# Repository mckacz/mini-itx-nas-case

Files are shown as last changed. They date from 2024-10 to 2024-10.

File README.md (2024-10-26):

# Mini-ITX NAS case

I've decided to design my own case because I could not find any suitable case for 
a mini-ITX motherboard with two 3.5 HDDs and no ATX power supply. :sunglasses:

| Render | Assembled |
|---|---|
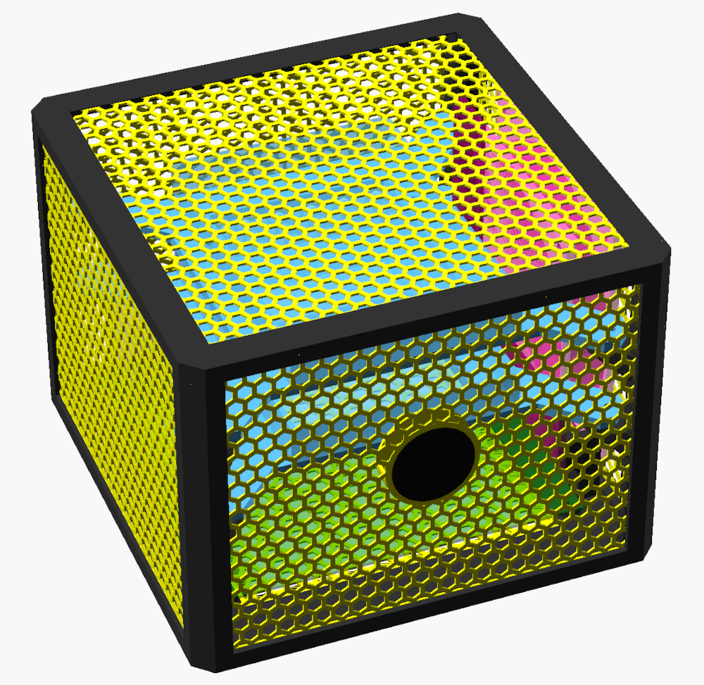
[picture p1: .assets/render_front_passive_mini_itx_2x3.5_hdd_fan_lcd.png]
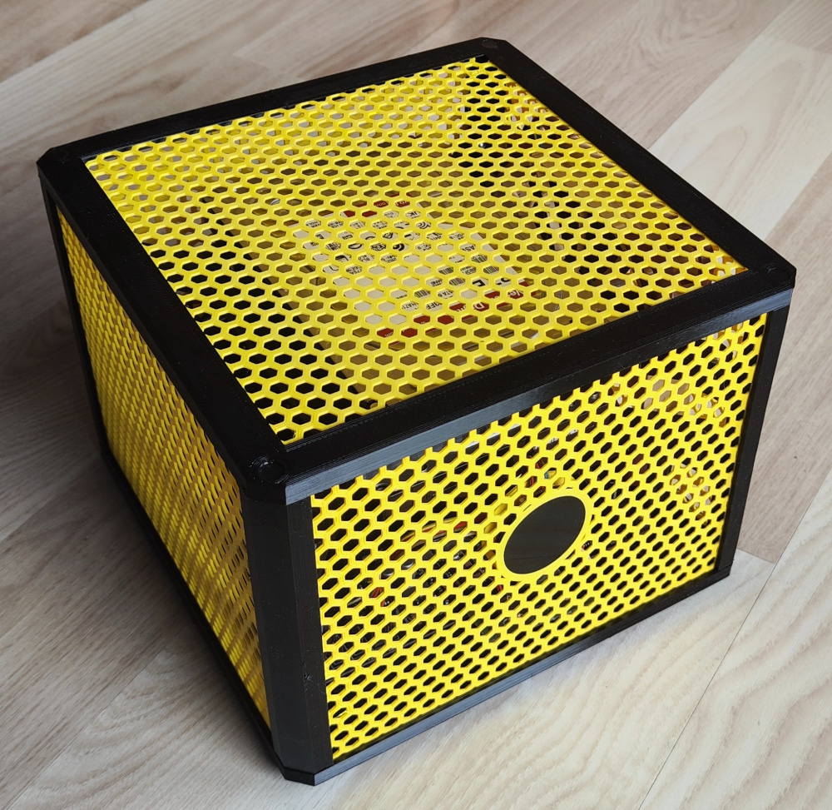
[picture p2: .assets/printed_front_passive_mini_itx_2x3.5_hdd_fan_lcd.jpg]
|  |  |
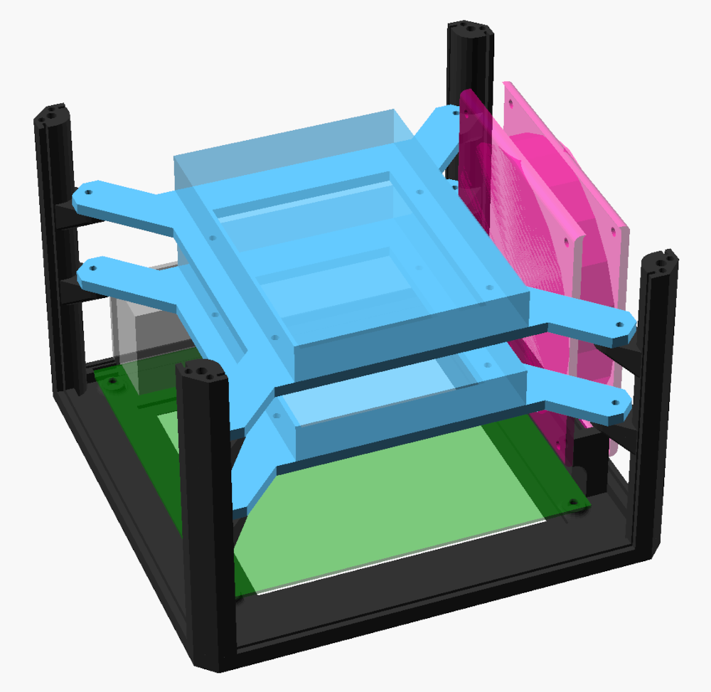
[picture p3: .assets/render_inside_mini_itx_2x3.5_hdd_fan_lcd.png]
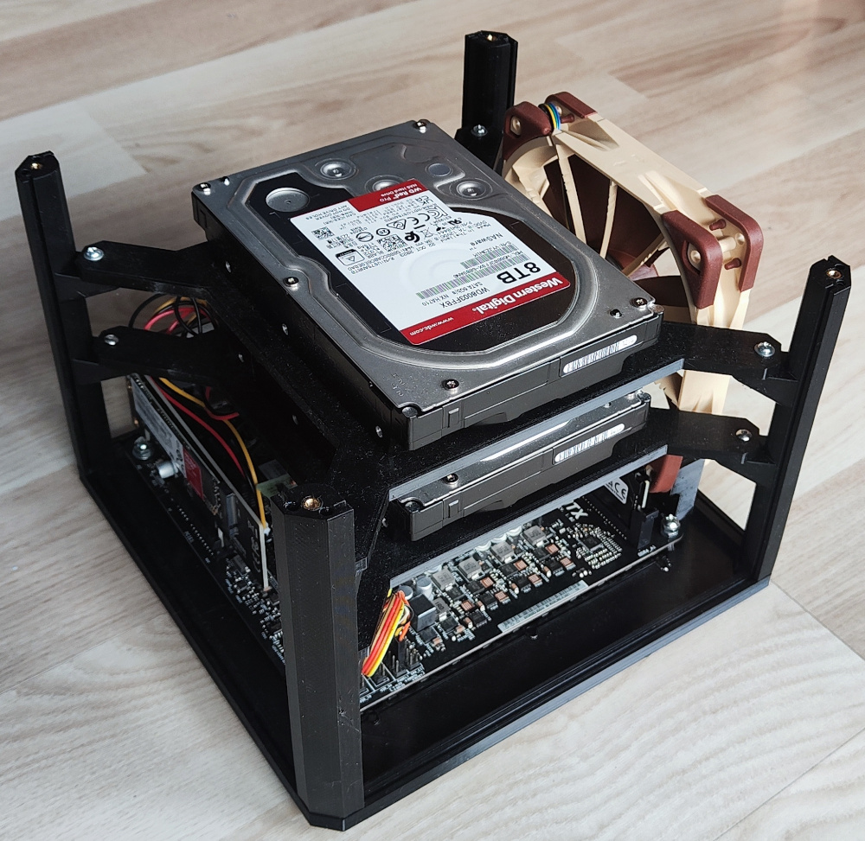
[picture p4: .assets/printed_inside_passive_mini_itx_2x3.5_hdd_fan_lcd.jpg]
|  |  |

## Features

* highly configurable (few configuration presents provided)
* support of mini-ITX motherboard with built-in power supply
* support of mini-ITX motherboard with Pico ATX power supply
* optional support for multiple 3.5" HDD drives
* optional support of 120mm case fan
* optional support of ESP32-S3-Touch-LCD-1.28 module used as a power button :metal:

## Pre-rendered variants

Check [stl](stl) folder for pre-rendered variants. 

## Customizing

1. Clone this repo
2. :warning: Download submodules:
    * `git submodule init`
    * `git submodule update`
3. Open [mini-itx-nas-case.scad](scad/mini-itx-nas-case.scad) and select base configuration preset (or create a new one)
4. You can override any variable defined in [base.scad](scad/config/base.scad)
5. Render all parts using OpenSCAD
   * :warning: do not render the whole case at once - it will not be printable
   * render each part separately - to render a single part, prefix it with `!` in [mini-itx-nas-case.scad](scad/mini-itx-nas-case.scad) and render

## Printing tips

* recommended material: `PETG` (`PLA` could bend if things get hot)  
* recommended material for case legs and caps: `TPU` 
* 0.6 nozzle is recommended to save some time 
* pillars and caps and legs must be printed in 4 copies
* only front panel with LCD slot requires support

## Assembly guide

1. print all parts 
2. glue top and bottom panels to top/bottom case part
    * :bulb: soldering borders using soldering iron also works well (join is invisible after assembly)
3. optionally glue legs to bottom part of the case
4. install brass inserts in bottom part and in all of the pillars
5. screw the motherboard to bottom part 
   * do not forget installing MB's backplate - later there would be no space for that
6. screw pillars to bottom part
7. if you have 3.5 HHD drive:
   * screw HDDs to frames
   * screw frames to pillars
8. install side panels
9. if using variant with fancy LCD module as a power button, follow [these](extra/ESP32-S3-Touch-LCD-1.28-firmware/) instructions 
10. screw top part to the pillars
11. optionally install caps to hide screws in top part

## Test setup

* **OS:** TrueNAS SCALE 24.04
* **Motherboard:** ASRock N100DC-ITX
* **Boot volume:** SSD WD Red SN700 250GB M.2 (yep, it's overkill. I know that now :see_no_evil:)
* **Apps volume:** SSD WD Red SN700 250GB M.2 using Ugreen PCIe 3.0 x4 M.2 PCIe NVMe expander
* **Data volumes:** 2x WD Red Pro 3.5" 8TB (mirror)
* **Fan:** Noctua NF-F12 PWM

Works well :rocket:

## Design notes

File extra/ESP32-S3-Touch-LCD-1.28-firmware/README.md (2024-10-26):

# ESP32-S3-Touch-LCD-1.28 as a power button

Not just a fancy power button.

## Features

* switch on/off the computer
* lock mode to prevent an accidental power switching (swipe to unlock)
* configurable colors and backlight 
* animated background to reduce LCD burn in
* accessible via Wi-Fi (switching power, settings, firmware update)
* automatic power on/off in configurable hours (with NTP time synchronization)



## Requirements

* [ESP32-S3-Touch-LCD-1.28](https://www.waveshare.com/wiki/ESP32-S3-Touch-LCD-1.28) module
* [PlatformIO](https://platformio.org/)

## Flashing guide

1. Update configuration to your needs, especially:
    * `WIFI_SSID` in [config.h](src/config.h#L4)
    * `WIFI_PASS` in [config.h](src/config.h#L5)
    * You could also want to update:
        * `OTA_HOST` in [config.h](src/config.h#L11) and `upload_port` in [platformio.ini](platformio.ini#L40)
        * `TIMEZONE` in [config.h](src/config.h#L15)
2. For the first time, you need to flash the module using USB cable
    * Flash web server files: `pio run -e esp32 -t uploadfs`
    * Flash the firmware: `pio run -e esp32 -t upload`
    * Later, you can flash over Wi-Fi
        * Flash web server files: `pio run -e esp32_remote -t uploadfsota`
        * Flash the firmware: `pio run -e esp32_remote -t upload`

## PCB board

To connect the module with the motherboard safely, you need the following
PCB ([schematic](https://easyeda.com/editor#project_id=74e369fe8bb940fa985d3b2512d9eb14)):

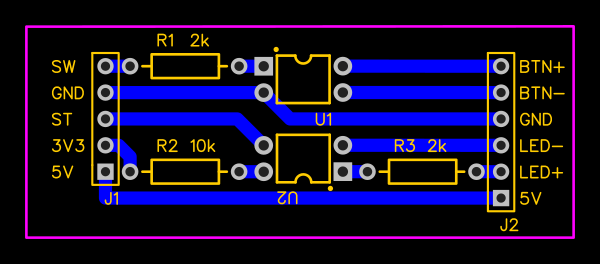
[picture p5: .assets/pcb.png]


### Parts:

* `U1`, `U2` - PC817 DIP4
* `R1`, `R3` - resistor 2k ohm THT
* `R2` - resistor 10k ohm THT
* `J1` - gold pin 1x5
* `J2` - gold pin 1x6

### Wiring

| Port | Pin name | Description | Connect to |
|---|---|---|---|
| `J1` | `SW` | Power switch signal | `GPIO 21` of the module |
| `J1` | `GND` | Ground | `GND` pin of the module |
| `J1` | `ST` | Power state signal  | `GPIO 33` of the module |
| `J1` | `3V3` | 3.3V | `3V3` pin of the module |
| `J1` | `5V` | 5V | `VSYS` pin of the module |
| `J2` | `BTN+` | Power button + | Power button + signal from the motherboard |
| `J2` | `BTN-` | Power button - | Power button - signal from the motherboard |
| `J2` | `GND` | Ground | Any ground from motherboard |
| `J2` | `LED-` | Power LED - | Power LED - signal from the motherboard |
| `J2` | `LED+` | Power LED + | Power LED + signal from the motherboard |
| `J2` | `5V` | 5V | Any 5V power supply from motherboard |

5V power supply from the motherboard should be always on to make the module work correctly.
Usually at least some USB ports provide 5V even the main supply is powered off.

### Accessing via browser

When module is configured correctly (Wi-Fi credentials), it can be accessed via the browser
using `http://[HOSTNAME].local` (default http://button.local).

Available options:

* switch the power on/off
* setup automatic power cycle:
    1. open options
    2. check `Auto on/off`
    3. optionally check `Power loss on`
        * the power will be restored after power loss in active hours (unless the power was turned off manually)
    4. setup power on hour (e.g `06:30`)
    5. setup power off hour (e.g `21:00`)

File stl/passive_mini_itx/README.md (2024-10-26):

### Case configuration

* fanless mini-ITX motherboard (like N100DC-ITX)
* no HDD (so only M.2 SSD)

### Dimensions

* width:  `210mm`
* depth:  `210mm`
* height: `63mm` (`58mm` without legs)

**Configuration file**: :point_right:
[passive_mini_itx.scad](../../scad/config/passive_mini_itx.scad)
:point_left:

### Additional parts

* 8x M3x6x4.5 brass insert + 8x M3x10 screw for case assembly
* 4x M4x4x6 brass insert + 4x M4x6 screw for mounting the motherboard

### Printing and assembly guide

Check the main :point_right: [README.md](../../README.md) :point_left:

### Preview

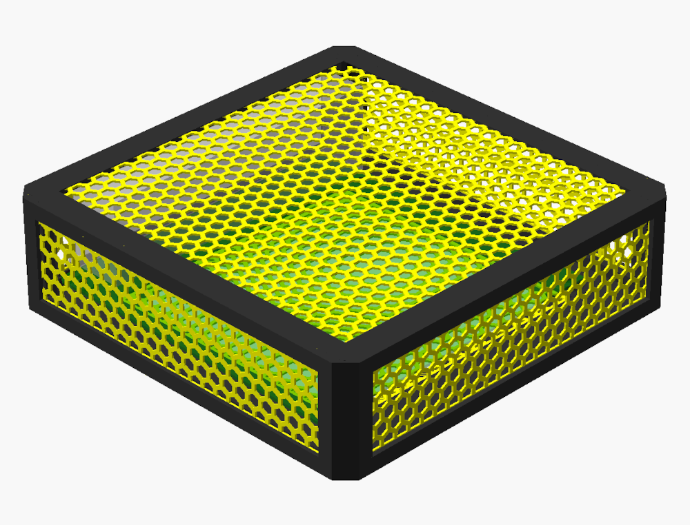
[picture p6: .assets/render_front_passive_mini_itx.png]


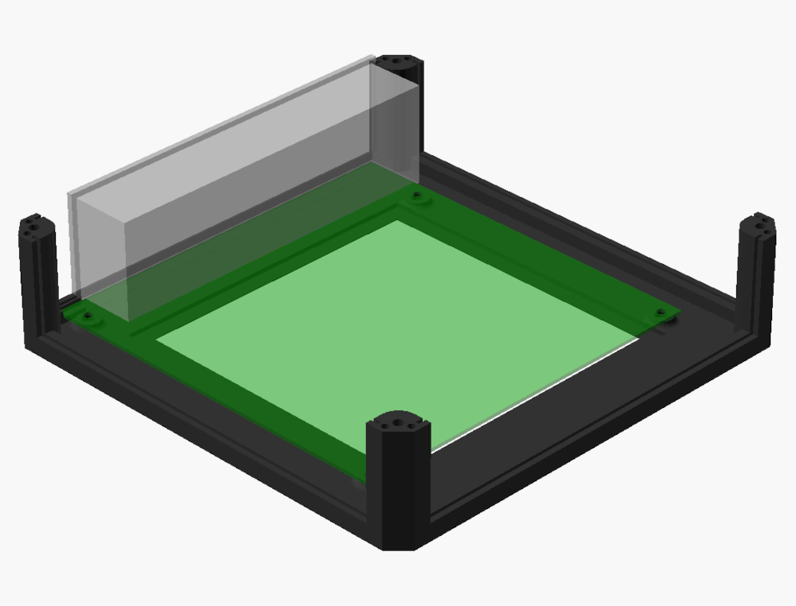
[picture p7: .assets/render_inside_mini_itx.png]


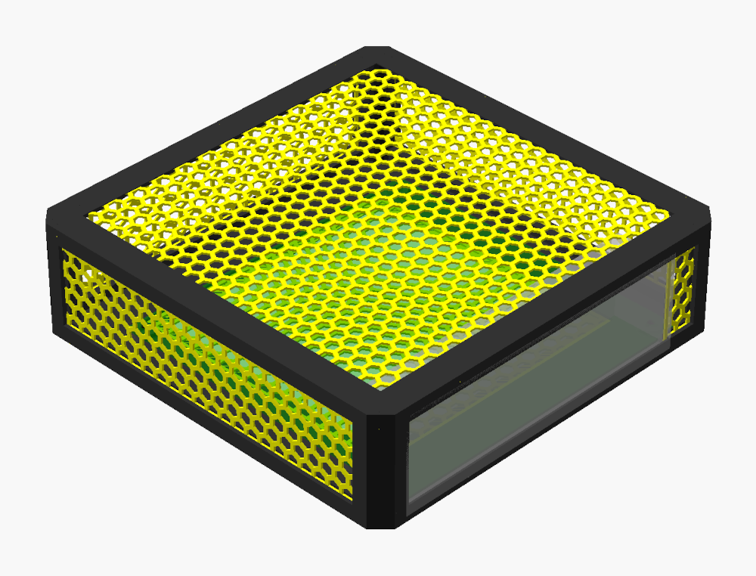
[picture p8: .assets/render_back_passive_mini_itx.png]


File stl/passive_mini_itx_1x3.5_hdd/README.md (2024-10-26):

### Case configuration

* fanless mini-ITX motherboard (like N100DC-ITX)
* 1x 3.5" HDD

### Dimensions

* width:  `210mm`
* depth:  `210mm`
* height: `111mm` (`106mm` without legs)

**Configuration file**: :point_right:
[passive_mini_itx_1x3.5_hdd.scad](../../scad/config/passive_mini_itx_1x3.5_hdd.scad)
:point_left:

### Additional parts

* 8x M3x6x4.5 brass insert + 8x M3x10 screw for case assembly
* 4x M4x4x6 brass insert + 4x M4x6 screw for mounting the motherboard
* 4x M3x3x4.5 brass insert + 8x M3x8 screw for mounting HDD frame to the case
* 4x UNC 6x10 screws for mounting HDD to HDD frame 

### Printing and assembly guide

Check the main :point_right: [README.md](../../README.md) :point_left:

### Preview

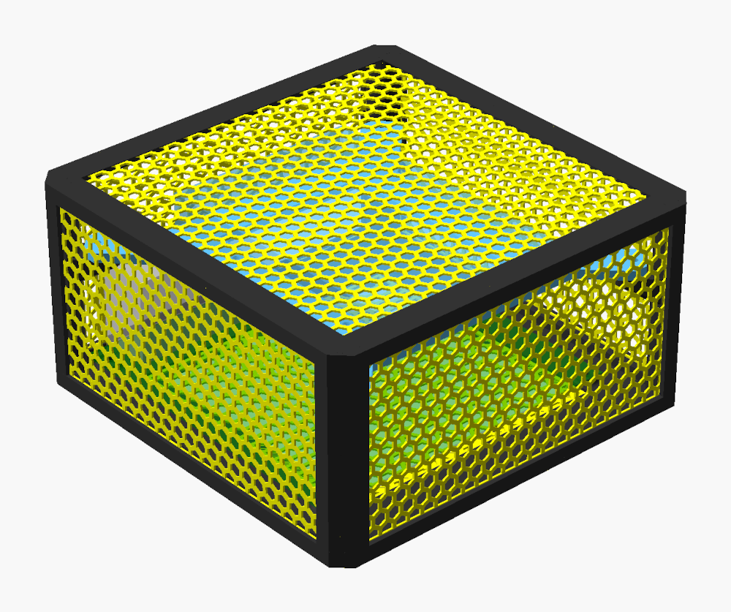
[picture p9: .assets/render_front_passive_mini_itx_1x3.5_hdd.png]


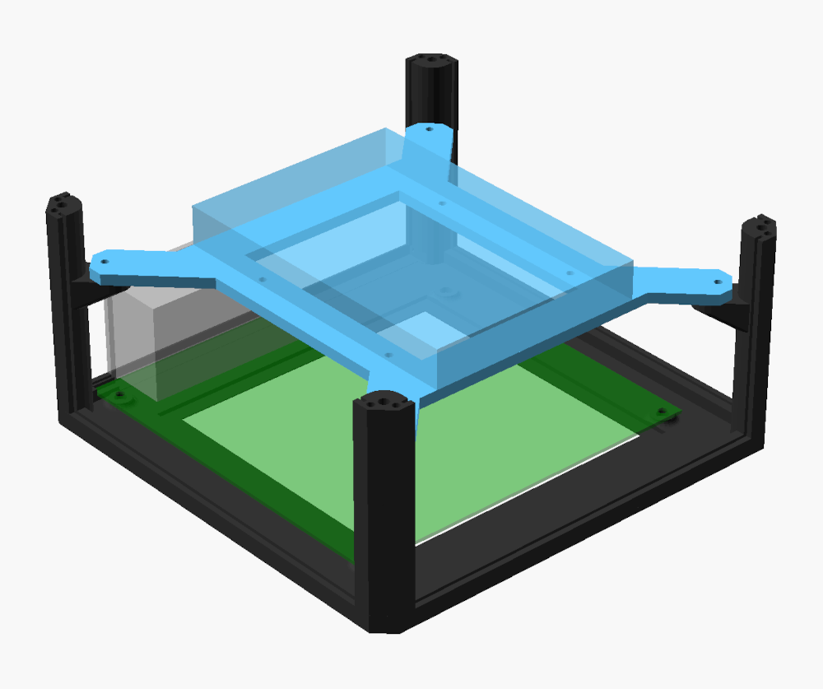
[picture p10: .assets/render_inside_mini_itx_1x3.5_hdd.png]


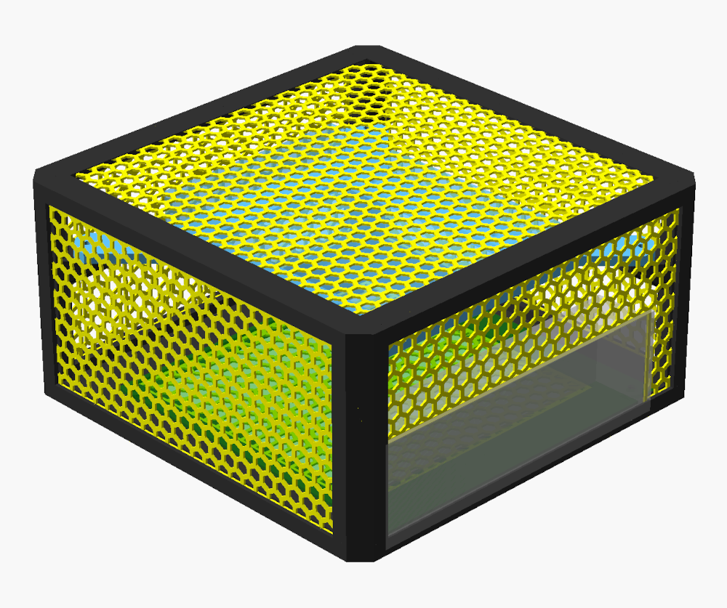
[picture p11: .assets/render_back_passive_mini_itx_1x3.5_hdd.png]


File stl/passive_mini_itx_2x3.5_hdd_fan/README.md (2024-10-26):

### Case configuration

* fanless mini-ITX motherboard (like N100DC-ITX)
* 2x 3.5" HDD
* 120mm fan

### Dimensions

* width:  `210mm`
* depth:  `210mm`
* height: `161mm` (`156mm` without legs)

**Configuration file**: :point_right:
[passive_mini_itx_2x3.5_hdd_fan.scad](../../scad/config/passive_mini_itx_2x3.5_hdd_fan.scad)
:point_left:

### Additional parts

* 8x M3x6x4.5 brass insert + 8x M3x10 screw for case assembly
* 4x M4x4x6 brass insert + 4x M4x6 screw for mounting the motherboard
* 8x M3x3x4.5 brass insert + 8x M3x8 screw for mounting HDD frame to the case
* 8x UNC 6x10 screws for mounting HDD to HDD frame 

### Printing and assembly guide

Check the main :point_right: [README.md](../../README.md) :point_left:

### Preview

| Render | Assembled |
|---|---|
|  | |
|  |  |
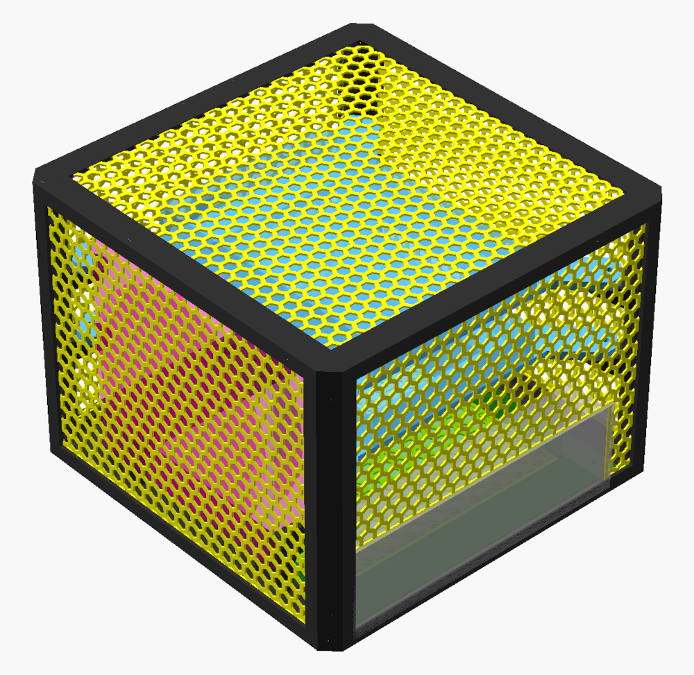
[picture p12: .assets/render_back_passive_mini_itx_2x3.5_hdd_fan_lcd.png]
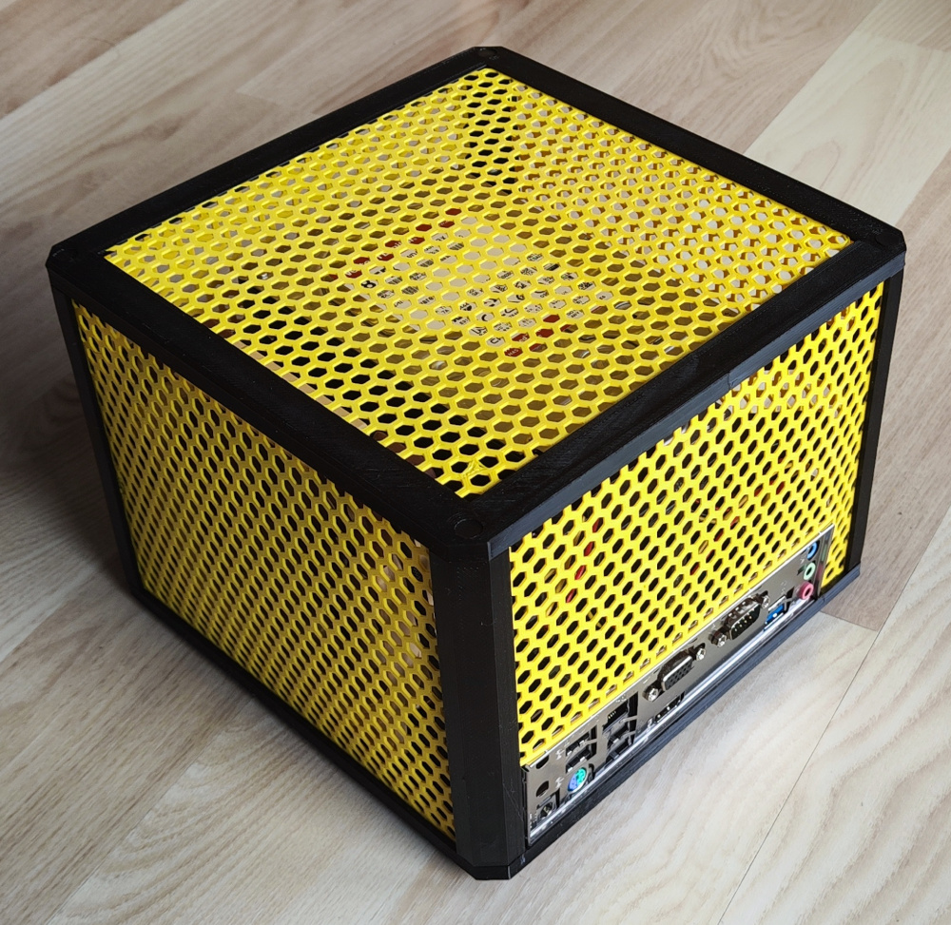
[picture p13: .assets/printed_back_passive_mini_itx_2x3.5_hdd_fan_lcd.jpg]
|  |  |

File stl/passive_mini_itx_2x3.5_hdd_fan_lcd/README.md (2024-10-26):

### Case configuration

* fanless mini-ITX motherboard (like N100DC-ITX)
* 2x 3.5" HDD
* 120mm fan
* ESP32-S3-Touch-LCD-1.28 on front panel as power button

### Dimensions

* width:  `210mm`
* depth:  `210mm`
* height: `161mm` (`156mm` without legs)

**Configuration file**: :point_right:
[passive_mini_itx_2x3.5_hdd_fan_lcd.scad](../../scad/config/passive_mini_itx_2x3.5_hdd_fan_lcd.scad)
:point_left:

### Additional parts

* 8x M3x6x4.5 brass insert + 8x M3x10 screw for case assembly
* 4x M4x4x6 brass insert + 4x M4x6 screw for mounting the motherboard
* 8x M3x3x4.5 brass insert + 8x M3x8 screw for mounting HDD frame to the case
* 8x UNC 6x10 screws for mounting HDD to HDD frame
* ESP32-S3-Touch-LCD-1.28 module

### Printing and assembly guide 

Check the main :point_right: [README.md](../../README.md) :point_left:

### Preview

| Render | Assembled |
|---|---|
|  |  |
|  |  |
|  |  |

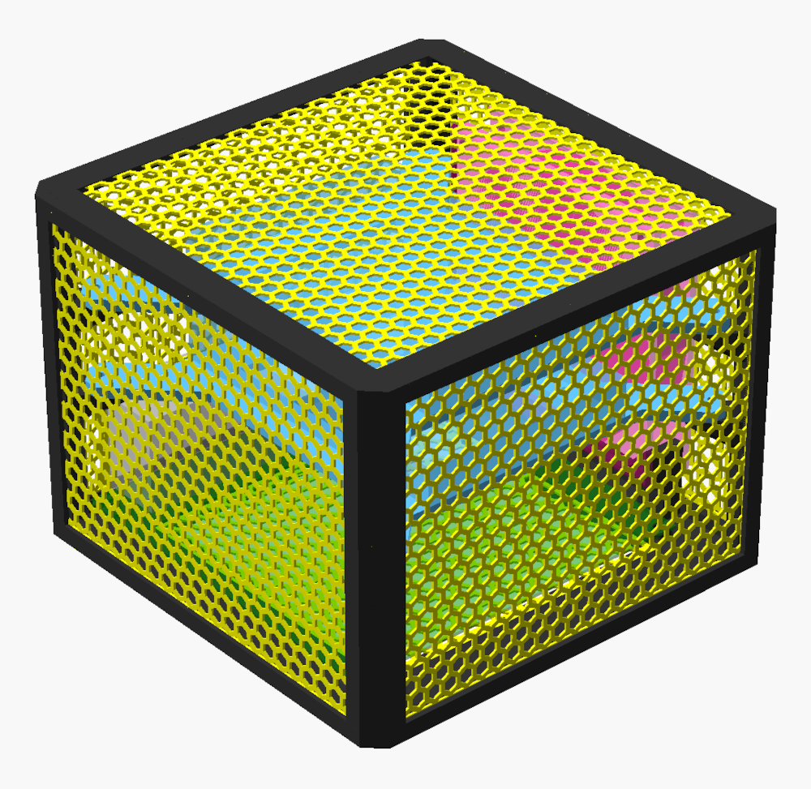
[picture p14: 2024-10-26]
.assets/render_front_passive_mini_itx_2x3.5_hdd_fan.png

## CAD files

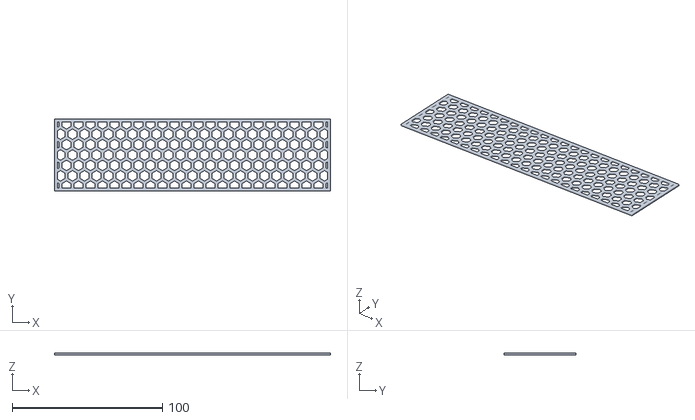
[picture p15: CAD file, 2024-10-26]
stl/passive_mini_itx/case_panel_front.stl
184.0 x 48.0 x 1.00

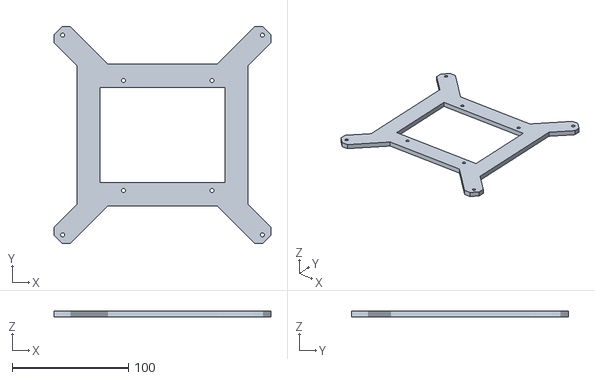
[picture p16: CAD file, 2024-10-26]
stl/passive_mini_itx_1x3.5_hdd/hdd35_frame.stl
186.4 x 186.4 x 5.00

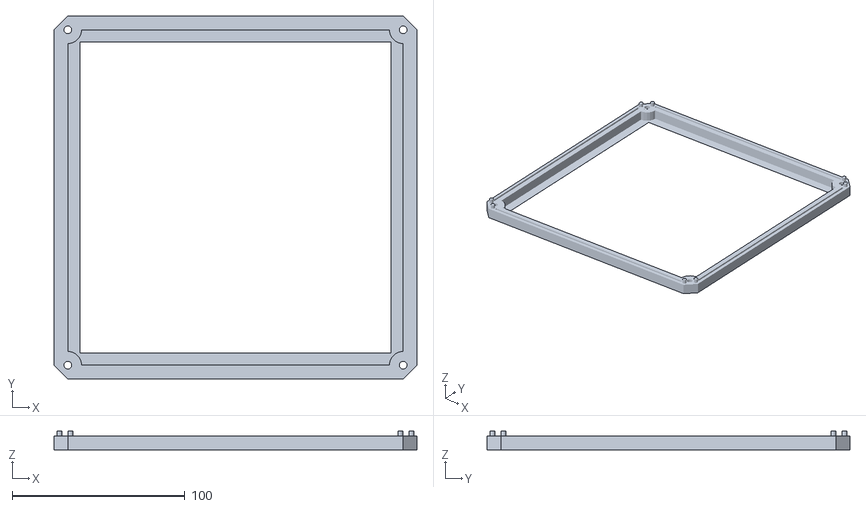
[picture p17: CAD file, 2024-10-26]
stl/passive_mini_itx_2x3.5_hdd_fan/case_top.stl
210.0 x 210.0 x 11.0

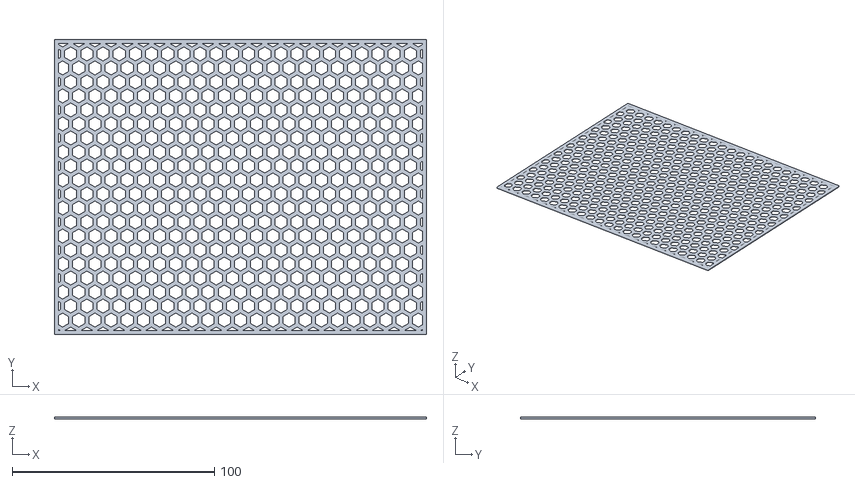
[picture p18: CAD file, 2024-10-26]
stl/passive_mini_itx_2x3.5_hdd_fan_lcd/case_panel_left.stl
184.0 x 146.0 x 1.00

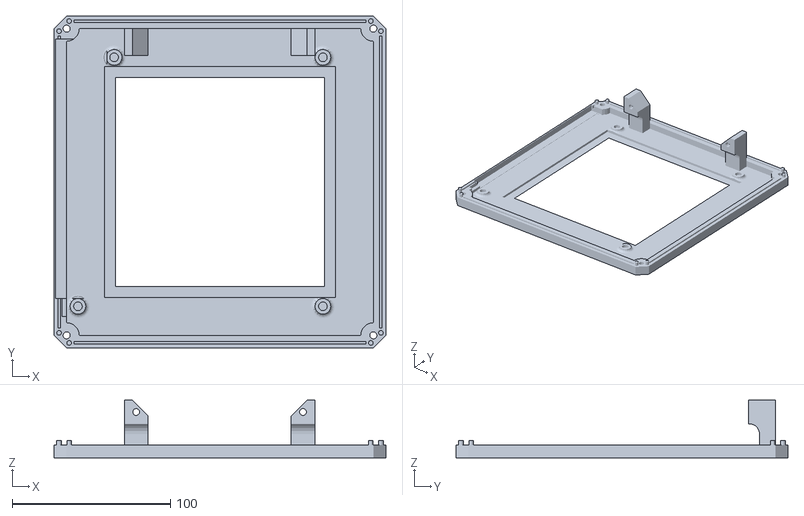
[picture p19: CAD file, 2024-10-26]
stl/passive_mini_itx/case_bottom.stl
210.0 x 210.0 x 36.5

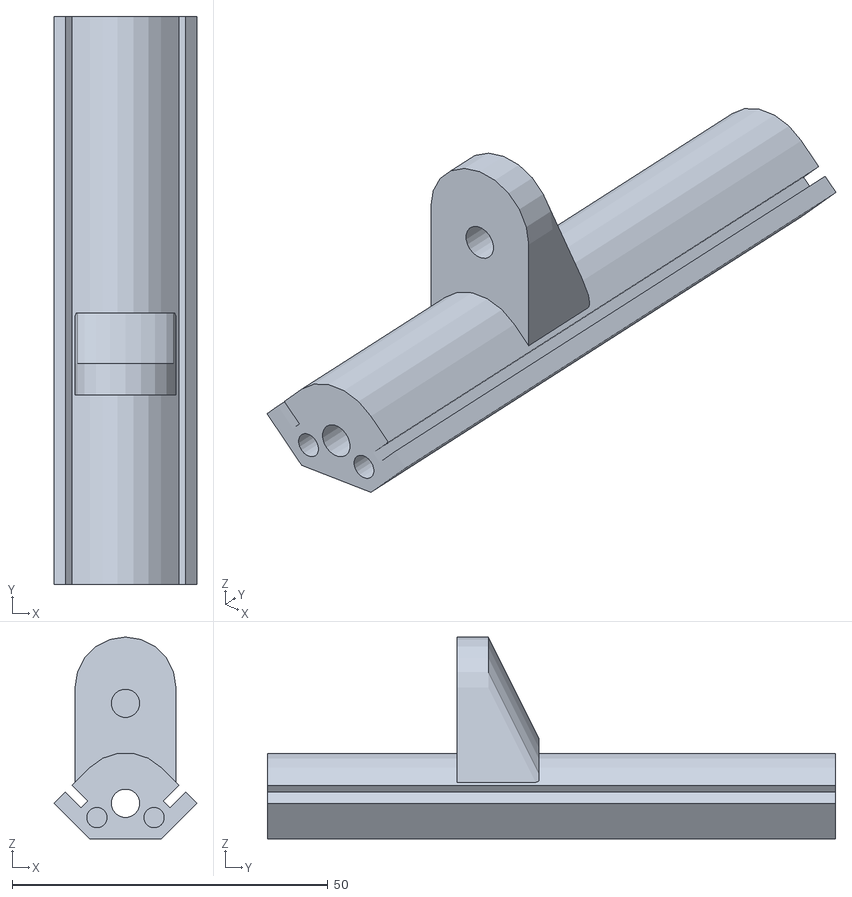
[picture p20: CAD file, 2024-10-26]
stl/passive_mini_itx_1x3.5_hdd/case_pillar.stl
22.6 x 90.0 x 32.0

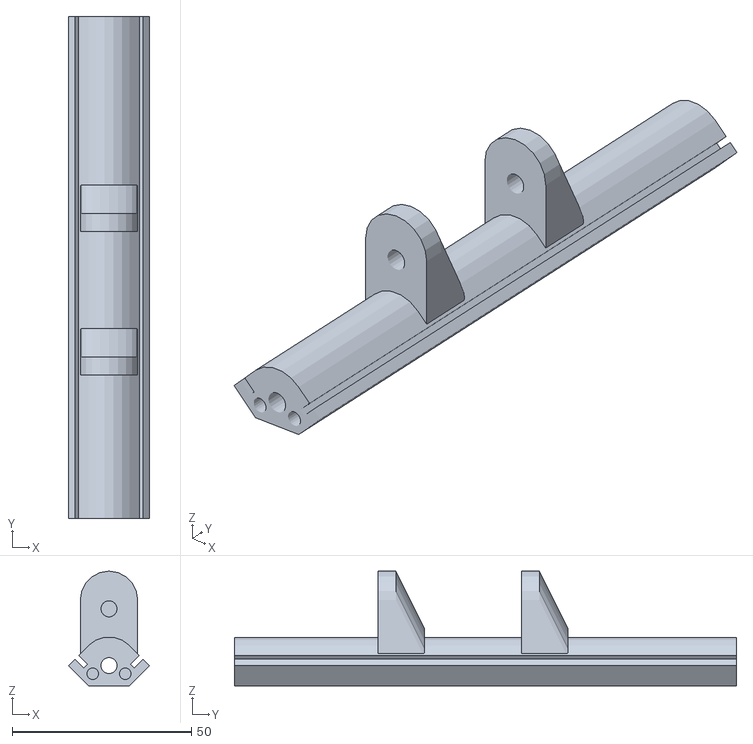
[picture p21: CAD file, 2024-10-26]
stl/passive_mini_itx_2x3.5_hdd_fan/case_pillar.stl
22.6 x 140.0 x 32.0

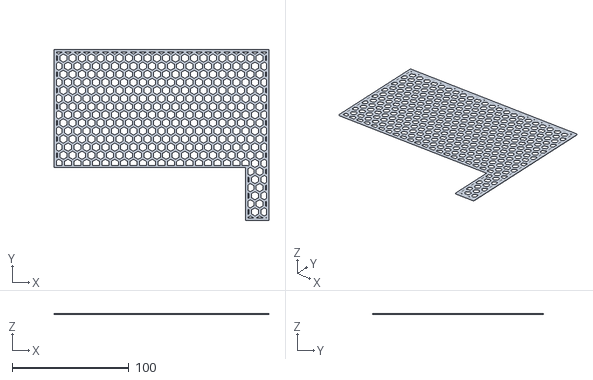
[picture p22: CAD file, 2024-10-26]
stl/passive_mini_itx_2x3.5_hdd_fan_lcd/case_panel_back.stl
184.0 x 146.0 x 1.00

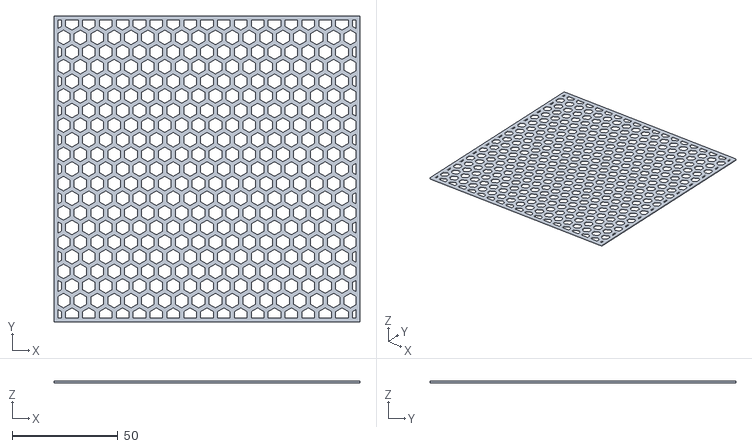
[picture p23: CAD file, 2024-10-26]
stl/passive_mini_itx_2x3.5_hdd_fan_lcd/case_panel_bottom.stl
145.0 x 145.0 x 1.00

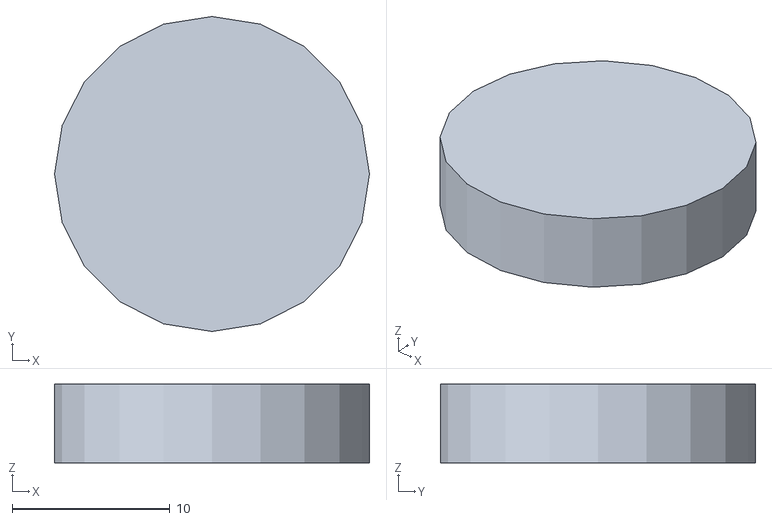
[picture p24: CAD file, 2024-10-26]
stl/passive_mini_itx/case_leg.stl
20.0 x 20.0 x 5.00

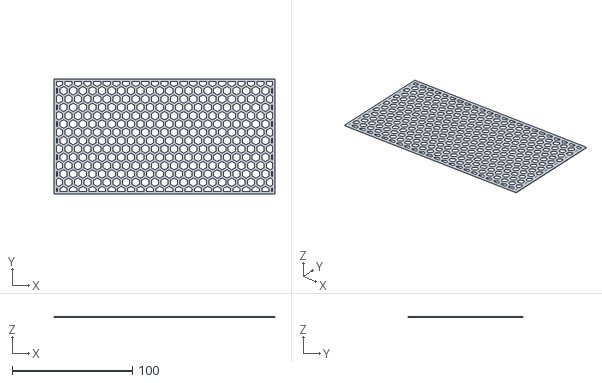
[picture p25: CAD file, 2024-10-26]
stl/passive_mini_itx_1x3.5_hdd/case_panel_right.stl
184.0 x 96.0 x 1.00

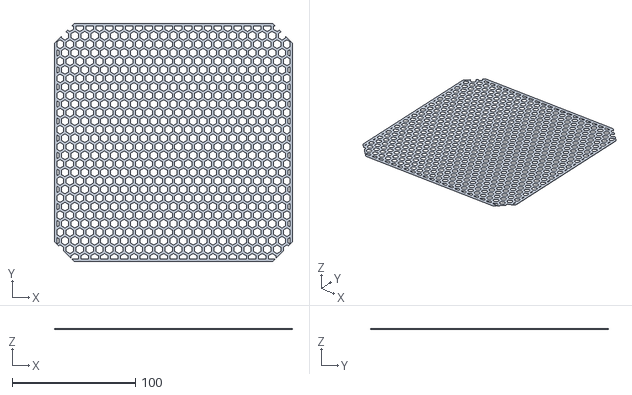
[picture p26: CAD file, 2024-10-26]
stl/passive_mini_itx/case_panel_top.stl
193.0 x 193.0 x 1.00

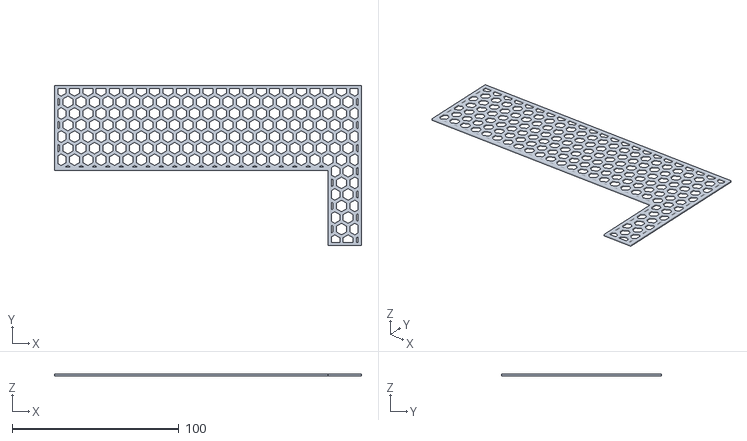
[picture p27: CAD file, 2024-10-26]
stl/passive_mini_itx_1x3.5_hdd/case_panel_back.stl
184.0 x 96.0 x 1.00

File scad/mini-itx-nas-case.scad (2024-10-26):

// Use only one configuration
//
// include <config/passive_mini_itx.scad>;
// include <config/passive_mini_itx_1x3.5_hdd.scad>;
// include <config/passive_mini_itx_2x3.5_hdd_fan.scad>;
include <config/passive_mini_itx_2x3.5_hdd_fan_lcd.scad>;
/////////////////////////////////////////////////////////

include <BOSL2/std.scad>;
include <BOSL2/walls.scad>;
include <lib/all.scad>;

// Do not render the whole case at once - it will not be printable.
// Render each part separately.
// To render a single part, prefix it with ! (exclamation mark) and render.

// skeleton
case_top();
case_top_caps(); // print 4 elements
case_pillars();  // print 4 elements
case_bottom();
case_legs();     // print 4 elements

// panels
case_panel_top();
case_panel_bottom();
case_panel_left();
case_panel_right();
case_panel_back();
case_panel_front();

// accessories
accessories() {
    hdd35_frame();
    hdd35_frame();
};

// motherboard
if ($preview) {
    mb();
}

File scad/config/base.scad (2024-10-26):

// ########
// # CASE #
// ########

// base dimensions of the case
case_dim = [210, 210];

// wall thickness
wall = 2.5;

// chamfer size
chamfer = 8;

// top/bottom belt size
z_belt = chamfer;

// top/bottom belt thickness
z_belt_thick = chamfer;

// bottom plate hex pattern - belt size around the pattern
bp_hex_belt = 32;

// bottom plate hex pattern - thickness of hexagonal bracing
bp_hex_strut = wall;

// bottom plate hex pattern -  center-to-center spacing of hex cells
bp_hex_spacing = chamfer;

// top/bottom plate socket diameter
bp_socket_diam = 8;

// top/bottom plate socket depth
bp_socket_depth = z_belt - 3;

// top plate belt
tp_belt = z_belt;

// socket cap diameter
socket_cap_diam = bp_socket_diam;

// socket cap thickness
socket_cap_thick = 2;

// ###########
// # PILLARS #
// ###########

// pillar shelves location (Z axis) for additional equipment
pillar_shelves = [];

// pillar width
pillar_width = chamfer * 2;

// pillar height
pillar_height = 42;

// pillar hole diameter (for insert)
pillar_hole_diam = 4.5;

// pillar shelf hole diameter (for insert)
pillar_shelf_hole_depth = 4;

// pillar shelf hole diameter (for insert)
pillar_shelf_hole_diam = 4.5;

// pillar thickness
pillar_thick = 5;

// pillar support thickness
pillar_support_thick = 8;

// pillar join diameter
pillar_joint_diam = 3;

// pillar joint extra diameter for female side
pillar_joint_extra = 0.25;

// pillar joint height
pillar_joint_height = 3;

// ##########
// # PANELS #
// ##########

// list of solid panels
panel_solids = [
//     "top",
//     "bottom",
//     "left",
//     "right",
//     "back",
//     "front",
];

// front panel with socket for ESP32-S3-Touch-LCD-1.28
panel_front_with_lcd = false;

// panel thickenss
panel_thick = 1;

// panel slot depth
panel_slot_depth = 3;

// panel slot wall
panel_slot_wall = 2;

// extra value added to panel slots
panel_extra = 0.5;

// panel hex pattern - belt size around the pattern
panel_belt = 2;

// panel hex pattern - thickness of hexagonal bracing
panel_hex_strut = panel_belt;

// panel plate hex pattern - center-to-center spacing of hex cells
panel_hex_spacing = 8;

// panel plate - pattern depth for solid panels
panel_solid_pattern_depth = 0.5;

// back panel cutout for motherboard
panel_back_cutout = [
    164,
    45,
    0,
    0,
];

// ##################
// # 3.5" HDD frame #
// ##################

// frame width
hdd35_frame_width = 20;

// frame thickness
hdd35_frame_thick = 5;

// hdd mount hole inner diameter
hdd35_frame_mount_hole_diam = 3.5;

// hdd mount hole outer diameter
hdd35_frame_mount_hole_outer_diam = 8;

// hdd mount hole depth
hdd35_frame_mount_hole_depth = 3;

// offset between hard disk and frame
hdd35_offset = [0, 0];

// #############
// # CASE LEGS #
// #############

// leg diameter
leg_diam = 20;

// leg height
leg_height = 5;

// leg slot offset from each side
leg_slot_offset = 15;

// ###########
// # BIG FAN #
// ###########

// enable fan mounts
fan = false;

// fan on left?
fan_on_left = false;

// fan size (assuming that fan is square)
fan_size = 120;

// fan thickness
fan_thick = 25;

// fan collar thickness
fan_collar_thick = 3.8;

// distance between screw holes
fan_hole_distance = 105.5;

// screw hole diameter
fan_hole_diam = 4.3;

// fan mount dimensions
fan_mount_size = [15, 10, 34];

// fan mount offset from case edge
fan_mount_y_offset = 8;

// ######################
// # MOTHERBOARD MOUNTS #
// ######################

// motherboard mount height
mb_mount_height = 5;

// inner diameter of motherboard mount (insert diameter)
mb_mount_inner_diam = 5.5;

// outer diameter of motherboard mount
mb_mount_outer_diam = 10;

// ###############
// # MOTHERBOARD #
// ###############

// motheboard dimensions
mb_dim = [170, 170, 1.6];

// motherboard offset relative to the center
mb_offset = [0, 0];

// motherboard keepout zone on Z axis
mb_ko = 5;

// motherboard mounting hole diameter
mb_hole_d = 4;

// motherboard mounting holes positions
mb_holes = [
    [10.16, 6.35, 0],   // ATX C
    [33.02, 163.83, 0], // ATX F
    [165.1, 6.35, 0],   // ATX H
    [165.1, 163.83, 0], // ATX J
];

// motherboard backplate dimensions
mb_bp_dim = [159, 45];

// motherboard backplate offset
mb_bp_off = [0, 13.87, 0.25];

// motherboard backplate keepout depth
mb_bp_ko = 25;

// motherboard backplate flange dimensions
mb_flange = 2.5;

// motherboard backplate flange offset from motherboard edge
mb_flange_off = 2.5;

// motherboard backplate flange wall
mb_flange_wall = 1;

// ###########
// # HELPERS #
// ###########

$fn = 20;
eps = 0.01;
extra = 1.0;

side_vectors = [
  [0, 0, 0],
  [1, 0, 90],
  [1, 1, 180],
  [0, 1, 270],
];

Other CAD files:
scad/config/passive_mini_itx.scad
scad/config/passive_mini_itx_1x3.5_hdd.scad
scad/config/passive_mini_itx_2x3.5_hdd_fan.scad
scad/config/passive_mini_itx_2x3.5_hdd_fan_lcd.scad
stl/passive_mini_itx/case_panel_back.stl
stl/passive_mini_itx/case_pillar.stl
stl/passive_mini_itx/case_top_cap.stl
stl/passive_mini_itx_1x3.5_hdd/case_top_cap.stl
stl/passive_mini_itx_2x3.5_hdd_fan/case_top_cap.stl
stl/passive_mini_itx_2x3.5_hdd_fan_lcd/case_panel_front.stl
stl/passive_mini_itx_2x3.5_hdd_fan_lcd/case_top_cap.stl

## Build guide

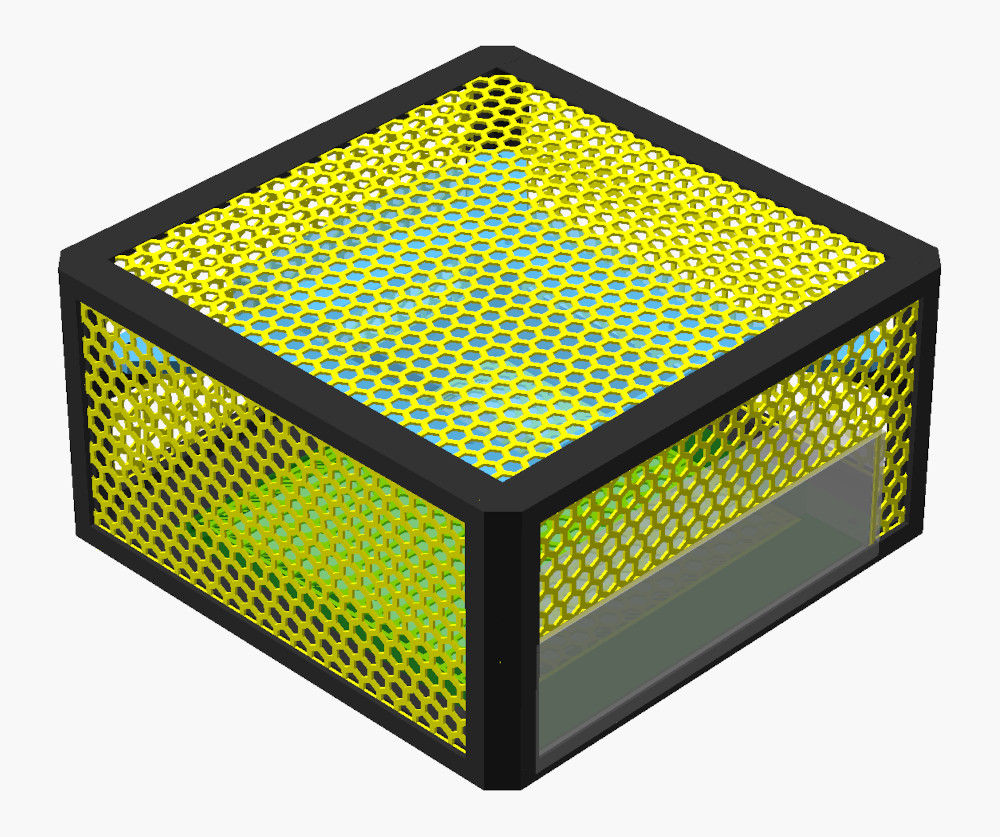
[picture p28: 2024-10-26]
.assets/printed_back_passive_mini_itx_1x3.5_hdd.jpg

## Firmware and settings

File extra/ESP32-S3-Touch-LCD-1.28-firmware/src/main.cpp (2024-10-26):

#include <Arduino.h>
#include "core/wifi.h"
#include "core/ota.h"
#include "core/datetime.h"
#include "io/io.h"
#include "lcd/lcd.h"
#include "ui/ui.h"
#include "view/view.h"
#include "scheduler/scheduler.h"
#include "web/web.h"

void setup() {
    Serial.begin(115200);
    Serial.println("Starting...");
    delay(1000);

    lcd_init();
    ui_init();
    view_init();
    io_init();
    ota_init();
    datetime_init();
    wifi_init();
    web_init();
    scheduler_init();
}

void loop() {
    wifi_loop();
    ota_loop();
    view_loop();
    lcd_loop();
    datetime_loop();
    io_loop();
    web_loop();
    scheduler_loop();
    delay(1);
}

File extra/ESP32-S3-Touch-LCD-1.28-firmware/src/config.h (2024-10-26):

#pragma once

// Wi-Fi credentials
#define WIFI_SSID "my_wifi_name"
#define WIFI_PASS "my_wifi_pass"

// Time after which the module will restart if it could not connect to the Wi-Fi (ms)
#define WIFI_RESTART_AFTER 30000

// Host name for OTA and web server
#define OTA_HOST "button" // should match `upload_port` for `esp32_remote` env in `platformio.ini`
#define OTA_PASS "hax0r"  // should match `auth` in `upload_flags` for `esp32_remote` env in `platformio.ini`

// Time zone
#define TIMEZONE "UTC"
// #define TIMEZONE "CET-1CEST-2,M3.5.0/2,M10.5.0/3" // Poland

// Pin to read power state
#define PWR_GET_PIN 33

// Pin to switch power state
#define PWR_SET_PIN 21

// Time of power switching pulse (ms)
#define PWR_PULSE_TIME 500

// Max. time of power changing (ms)
// Up to this time, switching animation will be displayed when powering off
#define PWR_DESIRED_TIMEOUT 30000

// Unlock hint display time
#define UNLOCK_HINT_TIMEOUT 2000

// Timeout after which the button will be locked automatically
#define LOCK_TIMEOUT 30000

// Required time of pressing to switch the power
#define PRESS_TIMEOUT 1000

// Timeout after which the backlight is switched to inactive state
#define BL_INACTIVE_TIMEOUT 30000

// PWM value of backlight for active state (0-255)
#define BL_ACTIVE 255

// PWM value of backlight for inactive state when powered on (0-255)
#define BL_INACTIVE_ON 192

// PWM value of backlight for inactive state when powered off (0-255)
#define BL_INACTIVE_OFF 0

// Hide UI when inactive and powered off (useful to avoid screen refresh when backlight is set 0)
#define BL_INACTIVE_HIDE_UI 1

// Indicator color when power off
#define COLOR_OFF_INDICATOR 0xAA0000

// Button color when power off
#define COLOR_OFF_MAIN 0xCC0000

// Indicator color when power on
#define COLOR_ON_INDICATOR 0x009900

// Button color when power on
#define COLOR_ON_MAIN 0x00CC00

// Indicator color when updating (OTA)
#define COLOR_UPDATE_INDICATOR 0x0000CC

// Indicator background color when updating (OTA)
#define COLOR_UPDATE_INDICATOR_BG 0x000033
